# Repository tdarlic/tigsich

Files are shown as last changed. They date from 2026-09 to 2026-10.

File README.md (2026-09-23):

# TIGSICH – index-finger slide remote for IPOTools SuperTIG 200Di

A passive, torch-mounted current control that replaces the IPOTools **FT-47K-CL8** foot pedal.
A **finger bar** under the index finger does both jobs. **Sliding** it moves a slide pot, which sets the welding current.
**Pressing** it clicks a push-on / push-off switch underneath, which starts or stops the arc at any current setting. The concept is the same
as the [6061 Slide Lever](https://www.6061.com/slidelever.htm).

> **Status: design rev 4, not yet prototyped. All board parts are in stock at Mouser (see section 7).** The socket voltages on the machine have **not been
> measured** yet. See [Open items](#open-items--before-first-use).

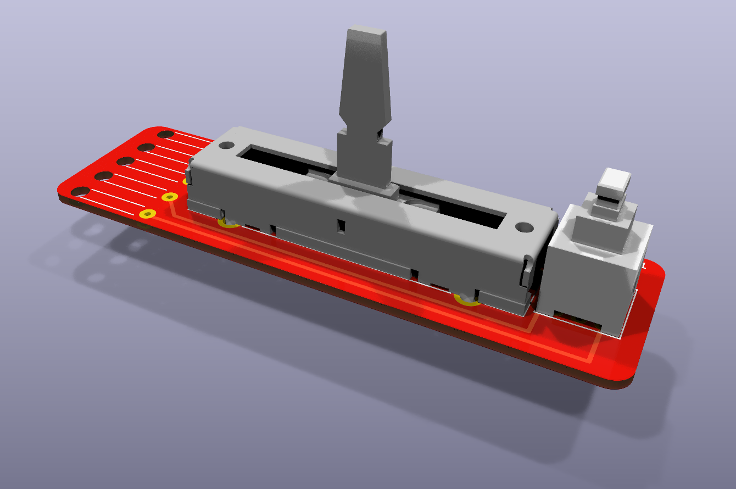
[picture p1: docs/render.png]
3D render of the board


Side view

| Schematic | PCB (top) | 3D top view |
|---|---|---|
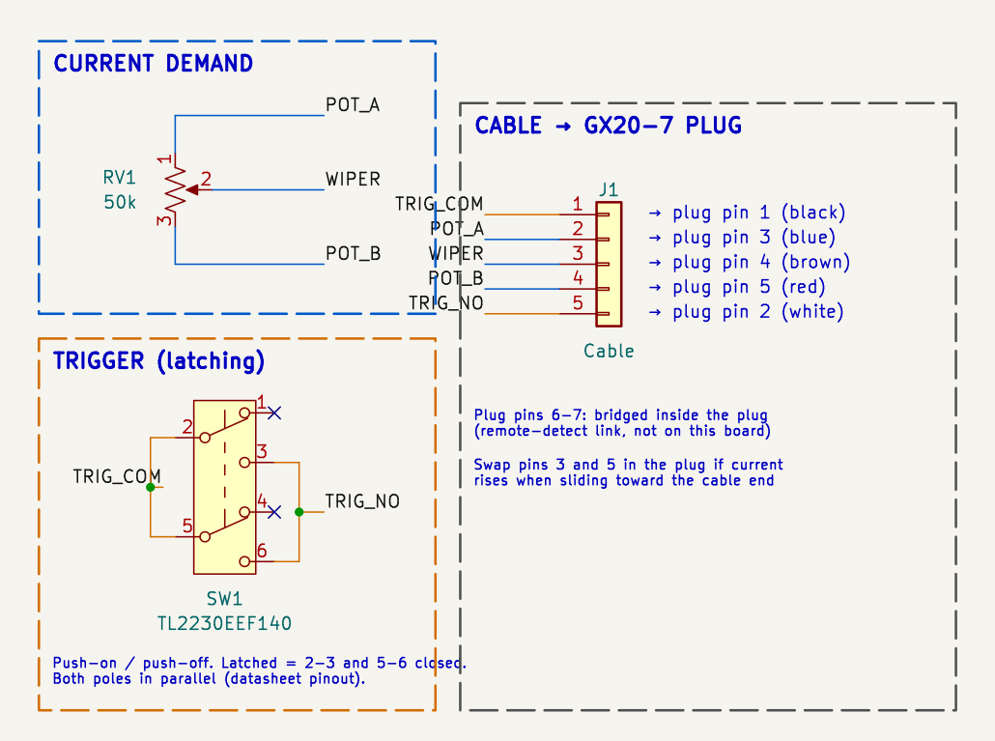
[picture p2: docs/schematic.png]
schematic
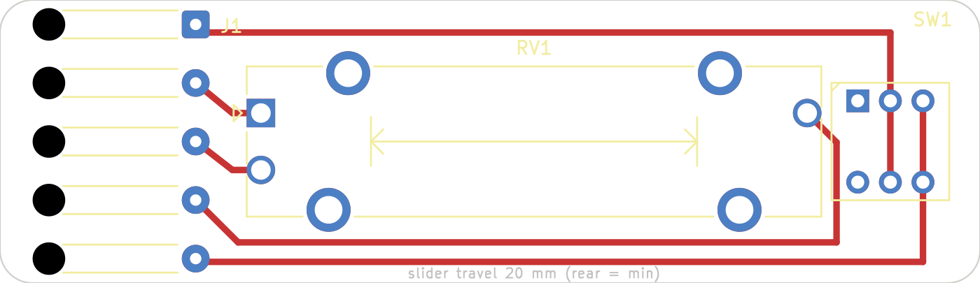
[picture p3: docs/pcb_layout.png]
pcb
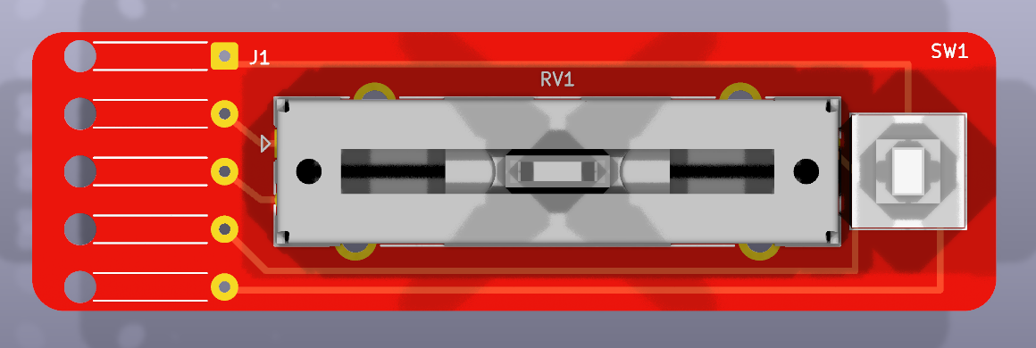
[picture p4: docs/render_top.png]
3d top
|  |  |  |

---

## 1. Machine interface

The machine has a GX20 7-pin remote socket. The pinout is the same one used by AHP/PrimeWeld pedals
(`configuration.jpeg`). It was confirmed by measuring the user's own FT-47K-CL8 pedal:

| Plug pin | Wire colour (diagram) | Function | Measured on FT-47K-CL8 |
|---|---|---|---|
| 1 | black | trigger contact | open → short when pedal pressed |
| 2 | white | trigger contact | 〃 |
| 3 | blue | pot end A | 3–4 and 4–5 swing 0.5 kΩ … 50 kΩ in opposite directions |
| 4 | brown | pot wiper | |
| 5 | red | pot end B | |
| 6–7 | – | remote-detect link | 0 Ω (bridged inside the plug) |

**Decisions based on this:**

- **Pot value 50 kΩ linear.** The pedal model name (47K) and the measurement (≈50 kΩ end to end) agree.
  The ±20 % pot tolerance doesn't matter, because the machine reads the wiper as a *ratio* of the reference voltage.
- **No series trim resistors.** The pedal's 0.5 kΩ minimum is simply the pot's residual resistance. The PTA datasheet
  specifies "500 Ω or 1 % max", which is exactly what the pedal shows.
- **Pins 6–7 are bridged inside the GX20 plug, not on the PCB.** This keeps the cable at 5 cores (thinner and more
  flexible on a torch).
- **The switch itself must latch.** IPOTools states the remote works **only in 2T mode**, so the machine's 4T
  latch can't be used with a momentary button.

### Supply voltage (assumed, not measured)

There is **no power pin** on this plug. The only voltages present are the pot reference (across 3–5) and the
trigger pull-up (across 1–2). Machines of this type typically put 5–15 V there, so the design
**assumes ≈12 V**. Because the design is passive, the voltage only has to stay within the parts' ratings:

| Part | Rating | Margin at 12 V |
|---|---|---|
| PTA2043 (20 mm, linear) | 200 V DC, 0.1 W | 12 V across 50 kΩ = 2.9 mW |
| TL2230 | 30 V DC, 100 mA | fine for a signal-level input |

---

## 2. Architecture

| Option | Outcome |
|---|---|
| Hall sensor + MCU + digital pot | **Rejected.** Needs power, and the plug has no supply pin. It would have to steal current from a 47 kΩ pot reference (≈0.2 mA) or use a battery. It also needs a high-voltage digital pot plus HF-start hardening. |
| Rev 1: finger lever (bell-crank) driving a slide pot | **Rejected on size.** A 35° swing needs a 25 mm drive arm to move the slider 15 mm, which put the lever top about 50 mm above the PCB. The board was 22.5 mm wide. |
| Rev 2: thumb slider + C&K PVA1 EE H4 latching button | **Rejected on height.** The PVA1 is 15 mm tall above the PCB, which set a 2 mm lid and a total height of about 20 mm. The target is under 15 mm. |
| Rev 3: index-finger bar + 15 mm PTA1543 | **Replaced on sourcing.** No 50 kΩ PTA1543 variant is stocked at Mouser (or LCSC). |
| **Rev 4: index-finger bar on the lug of a 20 mm PTA2043, pressing an E-Switch TL2230 latching button (chosen)** | Passive. One bar for both current and arc on/off. **≈14.7 mm** maximum height (bar top), 60.1 × 17.4 × 1.0 mm board. Every part in stock at Mouser. |

**How it's used:**

1. **Set the current:** slide the finger bar. Rear = minimum, front = maximum. It stays where you leave it, because the
   pot's own 30–250 gf friction holds it.
2. **Start the arc:** press the bar down. The switch underneath clicks and latches (plunger and bar stay 1 mm lower), closing pins 1–2.
   This works at **any slider position**, because the bar slides *over* the plunger.
3. **Change current while welding:** slide the bar; the latched switch stays on.
4. **Stop the arc:** press the bar again.

The machine stays in **2T mode**. The trade-off is that nothing stops the arc if you drop the torch: that takes a
deliberate press. The same footprint takes the momentary `TL2230OAF140` (hold to weld) if that's preferred.

---

## 3. Parts

| Ref | Part | Why |
|---|---|---|
| RV1 | **Bourns PTA2043-2015CPB503**: 20 mm travel, 50 kΩ linear, single gang, PC pins, **no centre detent**, 15 mm **metal (CP) lever** | The 15 mm PTA1543 we wanted isn't stocked at Mouser; this one is (≈ 900 pcs). Same series, pinout and ratings, with a 35 mm body (+5 mm board length). 20 mm travel ≈ 10 A/mm on a 200 A machine, which is finer control than 15 mm. **No detent:** the second digit `0` in `-2015…` (a `2` there means a centre detent). The metal **lever lug is cut down** to ≈ 13 mm above the PCB bottom and drilled for the finger-bar hinge pin (A); metal drills more cleanly than the insulated lever. |
| SW1 | **E-Switch TL2230EEF140**: DPDT, latching (EE), 140 gf, 7 × 7 mm, THT | The lowest latching switch with a proper datasheet that I found. Plunger top 12.5 mm above the PCB (11.5 mm latched). 1.0 mm to latch, 1.8 mm full travel. The datasheet shows the pinout and contact states explicitly. |
| J1 | Solder pads with strain-relief holes, **3.6 mm pitch** (`tigsich:SolderWire-0.15sqmm_1x05_P3.6mm…_Relief`, a copy of KiCad's 4 mm version) | No connector to shake loose on a torch. The wire passes up through a 2 mm hole before reaching its pad, so it's held in place. |
| Cable | 5 × 0.14 mm² flexible (insulation OD ≤ 1.5 mm), ~4 m, GX20-7 female plug | Same length as the original pedal (4.3 m). |

**Switches I compared** (button heights above the PCB bottom, for a 1.6 mm PCB; subtract 0.6 mm for the 1.0 mm board):

| Switch | Size (mm) | Button top: unlatched / latched | Verdict |
|---|---|---|---|
| C&K PVA1 EE H4 | 9.8 × 9.2 | 16.6 / 15.1 | Too tall (rev 2) |
| **E-Switch TL2230EEF140** | **7 × 7** | **14.1 / 13.1** | **Chosen** |
| Alps SPEF110100 | 12.2 wide, 9 deep | ≈ 14.6 unlatched | Wider, only 14.5 V DC rated |
| Generic 5.8 mm "self-lock" switches | 5.8 × 5.8 | similar | No trustworthy datasheet |

**Switch wiring:** both poles are in parallel. The TL2230 datasheet shows **rest = 1–2 and 4–5 closed**, and
**pushed / latched = 2–3 and 5–6 closed**. So **2 + 5 → TRIG_COM** and **3 + 6 → TRIG_NO**, and the rest contacts 1 and 4
are left unconnected. The two contacts in parallel give redundancy for a low-level signal.

**Switch life is the weak point.** The TL2230 is rated for **10,000 electrical cycles**, about 5,000 welds (on + off).
That's fine for hobby use, and it's a cheap THT part that's easy to replace.

**Pot life:** the PTA is rated at **15,000 slide cycles**. With a set-and-leave slider (rather than a pedal that moves on
every weld) that lasts a long time. A conductive-plastic slide pot of the same footprint is the upgrade path.

**No filtering or ESD parts on the board.** The original pedal is a bare pot and switch, and the machine's input
circuitry was designed for that. If HF-start interference shows up, the first fix is a shielded cable with the shield
grounded at the machine end.

---

## 4. Mechanics and heights (see `docs/mechanism.svg`)

**The finger bar:**

1. **Hinge at A:** its rear end is hinged on the cut pot lug with a pin (Ø ≈ 1 mm) through the lug, held by two
   clevis ears under the bar. Sliding the bar drags the pot slider.
2. **Resting on the switch:** its front part rests on the TL2230 plunger. The switch's own spring holds the bar up, so
   no extra return spring is needed.
3. **Pressing:** the bar tips about pin A. The distance from A to the switch is 12.5 mm at MAX and 32.5 mm at MIN, so the
   1.8 mm switch travel is a 3.2–8.2° tilt. A rigid joint at A won't work; it has to be a hinge (or a printed flexure).
4. **Finger pad:** at the front end, 38 mm from A, just in front of the switch. Pressing close to the switch keeps the
   lifting force on the pot lug small. (Pressing far in front of the switch levers the lug *up*.)

**Lid features around the switch:**

- **Square bore:** a close-fitting bore round the plunger (3.0 × 2.0 mm head) takes the **sideways friction** as the bar slides across the
  plunger top, so the switch stem isn't bent. A smooth bar underside (polished aluminium, or PTFE tape) helps too.
- **Side rails:** two rails beside the bore keep the bar centred (it can't swing sideways around A).
  Their tops are the **down-stop** at ≈ 1.7 mm switch travel. That's past the 1.0 mm latch point and short of the 1.8 mm end stop.

All heights are measured from the PCB bottom, using nominal datasheet values, with a **1.0 mm PCB**:

| Item | Height |
|---|---|
| PCB | 1.0 mm |
| Pot body top | 7.5 mm |
| TL2230 body top | 8.0 mm |
| Lid (1.5 mm), resting just above the switch body | 8.2 → **9.7 mm** |
| Hinge pin A (in the cut lug) | ≈ 12.2 mm |
| Plunger top = bar underside (unlatched / latched) | 13.5 / 12.5 mm |
| **Finger bar top** (1.2 mm bar), highest point | **≈ 14.7 mm** (13.7 mm latched) |

**The height target (< 15 mm) is met.** A 1.6 mm PCB would add 0.6 mm (≈ 15.3 mm). A 1.5 mm aluminium bar would add another
0.3 mm. Add the housing floor under the PCB (≈ 1–1.5 mm) to get the total thickness on the torch.

**Other housing notes:**

- **Bar overhang:** the bar is 38 mm from A to its front end, so it reaches ≈ 60.8 mm (MIN) to ≈ 80.8 mm (MAX) from the
  rear edge. At MAX it sticks out ≈ 18 mm past the housing front, toward the torch head.
- **Lid slot:** the slot for the pot lug is 20 mm of travel plus the lug width (check on the part, ≈ 5 mm), so about 25 mm long. The clevis
  ears and the bar cover it at every position; a thin skirt on the ears keeps dust out of the pot.
- **Lid fixing:** the lid screws into the pot's two **M2 threaded holes** (on top of the pot frame, 31 mm apart on the PTA2043).
  This clamps lid, pot and PCB into one stack. The PCB has **no mounting holes**, because there's no room at 17.4 mm wide.
  The PCB rests in grooves or on ribs in the housing floor, which also carry the press force.
- **Mounting on the torch:** two strap or zip-tie slots in the housing floor. The cable exits at the rear, alongside the torch hose.

---

## 5. PCB

- **Board:** **60.1 × 17.4 mm**, 2 layers, **1.0 mm** (chosen to keep the finger bar under 15 mm), rounded corners (R2), 0.4 mm tracks (signal-level currents).
  All copper is on the top layer, with no vias. There is no ground plane: the circuit has no ground.
- **Width:** the 17.4 mm is set by the 5-pad cable column: 14.4 mm of pads at **3.6 mm pitch**, plus the 1.7 mm pad size
  and 0.65 mm edge clearance. The 2.0 mm strain-relief holes still take wires with insulation up to 1.5 mm OD, leaving
  1.6 mm of board between neighbouring holes. The pot is 11 mm wide including its tabs, and the switch 7 mm. The two track
  lanes under the pot sit between the pot's mounting tabs and the board edge, with ≥ 0.45 mm clearance.
- **Layout, rear to front (cable → torch head):**
  1. **Cable pads (J1):** at the rear edge.
  2. **Slide pot (RV1):** its slider runs along the board centreline.
  3. **Latching button (SW1):** centred, 0.85 mm in front of the pot body.
- **Routing:** the pot and switch connections that pass alongside the pot run in lanes above and below the pot body.
- **Pot direction:** RV1 pin 1 (the rear end) connects to plug pin 3, so the **rear slider position = wiper next to
  plug pin 3**, i.e. P3–P4 ≈ 0.5 kΩ. If the machine gives *maximum* current at the rear, swap the wires on plug pins 3 and 5.
- **J1 pad order** (top to bottom) is chosen so nothing crosses. It's printed on the **bottom** silkscreen next to each pad:

| J1 pad | Silk | Net | Plug pin | Diagram colour |
|---|---|---|---|---|
| 1 | P1 | TRIG_COM | 1 | black |
| 2 | P3 | POT_A | 3 | blue |
| 3 | P4 | WIPER | 4 | brown |
| 4 | P5 | POT_B | 5 | red |
| 5 | P2 | TRIG_NO | 2 | white |

- **PTA2043 footprint: corrected copy of KiCad's.** KiCad's `Potentiometer_Bourns_PTA2043_Single_Slide` puts pin 3 at
  **33.0 mm** from pin 1, but the datasheet (dimension E) and Bourns' STEP model both give **33.5 mm**. With Ø1.2 mm holes
  and 0.8 mm pins, the library version would not let the pot seat. The project copy
  (`tigsich.pretty/Potentiometer_Bourns_PTA2043_Single_Slide_E33.5`) keeps pins 1/2 where they were, moves pin 3 to
  33.5 mm, and shifts the four mounting tabs and body outline by +0.25 mm, so everything is centred at 16.75 mm as on the part.
- **TL2230 footprint:** it's custom (`tigsich.pretty/SW_E-Switch_TL2230`), because KiCad's library doesn't have one.
  It was made from the datasheet PCB layout (component side): 2 rows of 3 × Ø0.8 mm holes, 2 mm pitch, rows 5 mm apart,
  pin 1 square. The pad numbers match the `Switch:SW_Push_DPDT` symbol: B = common 2/5, A = rest 1/4, C = pushed 3/6.
- **3D models:**
  - **SW1** uses E-Switch's own STEP model (`tigsich.3dshapes/TL2230xxFxxx.stp`, inch units). It is set in the footprint
    with a 90° rotation (the vendor model has its pin rows along Y) and a +0.75 mm Z offset (model origin is 0.75 mm above
    the seating plane). With these, the pins sit centred in the pads and the plunger top is 12.5 mm above the PCB, as in
    the datasheet.
  - **RV1** uses Bourns' STEP model (`tigsich.3dshapes/PTA2043-2015DPB103.stp`, mm). Its "up" is −Z and pin 2 is at +Y,
    so the footprint flips it 180° about X and offsets it by (−0.85, +2.9, 0) mm. That centres the body on the tabs and puts
    all pins and tabs in their holes, with the body seated on the board.
  - **Caution for the housing:** Bourns only offered the model for the **DP** lever variant (`…DPB103`). We order
    **CP** (`PTA2043-2015CPB503`). The body, pins and slot are identical, but **the lever shape differs** (the DP lever in
    the model reaches ≈ 20.7 mm above the PCB top). Take the lever dimensions for the case from the datasheet's CP lever drawing,
    or measure the real part. The lever is cut down anyway.

**Verification:**

- **ERC:** 0 violations.
- **DRC:** 0 violations, 0 unconnected, 0 schematic-parity issues.
- **Tool:** KiCad 10.0.6.

---

## 6. Files

| Path | Content |
|---|---|
| `tigsich.kicad_pro/.kicad_sch/.kicad_pcb` | KiCad project |
| `tigsich.pretty/` | Project footprints: TL2230, corrected PTA2043 (E = 33.5 mm), 3.6 mm pitch cable pads |
| `tigsich.3dshapes/` | Vendor STEP models: TL2230 (E-Switch), PTA2043 DP-lever variant (Bourns) |
| `docs/mechanism.svg` | Scaled side view: finger bar, hinge, switch, heights |
| `docs/schematic.pdf` / `.png` | Schematic exports |
| `docs/render.png`, `docs/render_top.png`, `docs/pcb_layout.png` | 3D renders (KiCad, vendor STEP models) and copper/silk plot |
| `configuration.jpeg` | 7-pin plug pinout reference |

---

## 7. Bill of materials (Mouser)

Stock and prices were checked on 2026-09-23 through the pcbparts MCP (Mouser API, USD).

| Ref | Qty / unit | Spare | Manufacturer part | Mouser no. | Stock | Price (USD) |
|---|---|---|---|---|---|---|
| RV1 | 1 | +2 (lug cutting / drilling trials) | Bourns **PTA2043-2015CPB503** | 652-PTA20432015CPB50 | 893 | 1.76 (1+), 1.35 (10+) |
| SW1 | 1 | +9 (wear part, 10k cycles) | E-Switch **TL2230EEF140** | 612-TL2230EEF140 | 4,614 | 0.85 (1+), 0.75 (10+) |
| – | 1 reel (5,000) | – | YAGEO **RC0603FR-07100KL** (100 kΩ 1 % 0603, general stock, not used on this board) | 603-RC0603FR-07100KL | 5.1 M | 0.003 (5,000+) |

The Mouser order comes to ≈ $30, under Mouser's EU free-shipping threshold (≈ €50). Mouser ships to the EU with duty and VAT included,
so there's no customs agent. Add other stock parts to reach the threshold.

**Not at Mouser** (buy elsewhere):

| Item | Suggested source |
|---|---|
| Cable 5 × 0.14 mm², ~4.3 m | LAPP UNITRONIC LiYY 5x0.14 (LAPP 0028205) at TME, or any flexible 5-core; shielded LiYCY 5x0.14 (0034305) if HF-start noise appears |
| GX20 7-pin female cable plug | Generic "aviation" connector (local shop, Amazon.de/eBay), or reuse the FT-47K-CL8 pedal's plug; bridge pins 6-7 inside |
| PCB 60.1 × 17.4 × 1.0 mm, 2 layers | Any EU/CN PCB fab (thickness 1.0 mm must be specified) |
| Hinge pin Ø 1 mm, M2 screws ×2 (lid → pot), finger bar 1.2 mm | Hardware store / printed or machined parts |

---

## Open items / before first use

1. **Measure the socket.** With the machine on and the pedal unplugged, measure the DC voltage across 3–5, across 1–2, and from
   each pin to the case. It must be **≤ 30 V** on 1–2 for the TL2230. Don't strike an arc (HF start) while probing.
2. **Check the switch.** Before soldering, check with a meter that the TL2230 closes 2–3 (and 5–6) only when latched.
   On the finished board, check that P1–P2 is open when the button is up and closed when it's latched.
3. **Check the pot direction:** the rear slider position should give minimum current. Swap plug pins 3/5 if needed.
4. **Check part dimensions** against real parts. The TL2230 plunger height sets the bar height, and the pot lug is
   cut and drilled to suit the hinge.
5. **Design the housing and bar:** lid with lug slot, plunger bore, side rails and down-stop, M2 screws into the pot,
   finger bar with clevis ears and hinge pin, PCB grooves, strap slots, cable gland.
6. **Check the latch through the bar:** make sure a press anywhere in the 20 mm travel latches and unlatches the switch
   reliably, and that sliding while latched doesn't unlatch it.
7. **Test first on scrap:** check minimum and maximum current, that the latch works with gloves on, and that HF start
   doesn't cause flicker. If it does, use a shielded cable.

## Sources

- [SSC C910-0725 info sheet (same 7-pin pinout)](https://ssccontrols.com/uploads/Product-Information-Sheet-C910-0725-TIG-Foot-Controls.pdf)
- [IPOTools FT-47K-CL8 foot pedal](https://ipotools.eu/product/tig-foot-pedal/)
- [Bourns PTA series datasheet](https://www.bourns.com/docs/product-datasheets/pta.pdf)
- [E-Switch TL2230 datasheet](https://configured-product-images.s3.amazonaws.com/Datasheets/TL2230.pdf)
- [E-Switch TL2230 product page](https://www.e-switch.com/product-catalog/tl2230-series-subminiature-pushbutton-switch)
- [C&K PVA series datasheet (rev 2)](https://www.mouser.com/datasheet/2/240/pva-3050984.pdf)
- [Alps SPEF series (compared)](https://tech.alpsalpine.com/e/products/category/switches/sub/03/series/spef/)
- [6061 Slide Lever (concept reference)](https://www.6061.com/slidelever.htm)

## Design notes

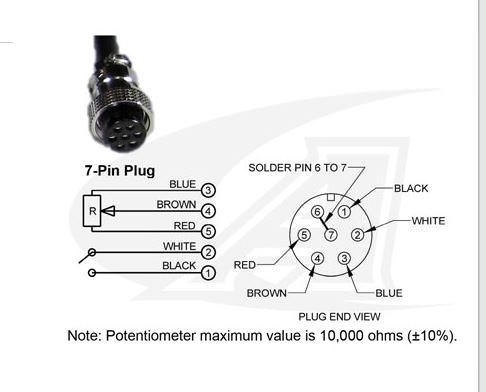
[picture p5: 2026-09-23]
configuration.jpeg

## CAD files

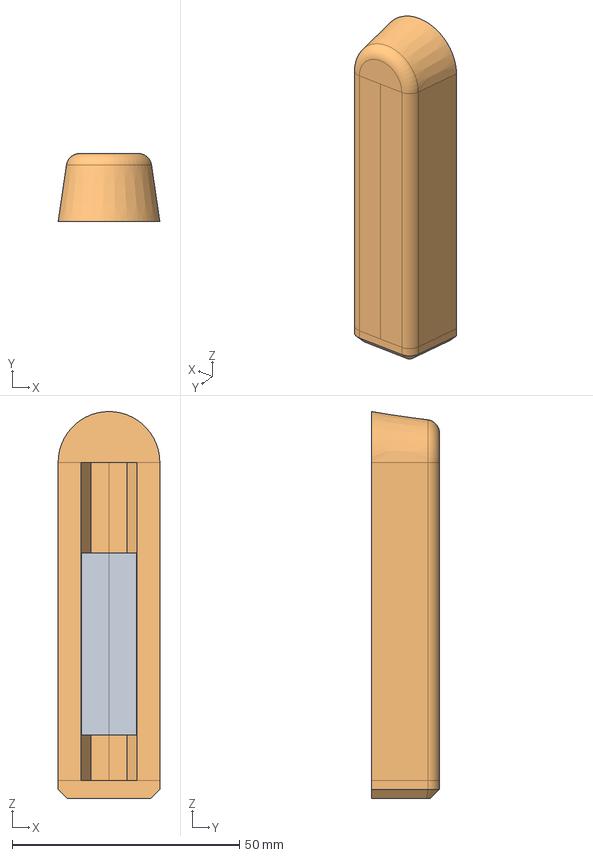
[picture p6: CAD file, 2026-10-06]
hardware/slider_test.step
22.4 x 15.0 x 85.2 mm
Podnozje
botun

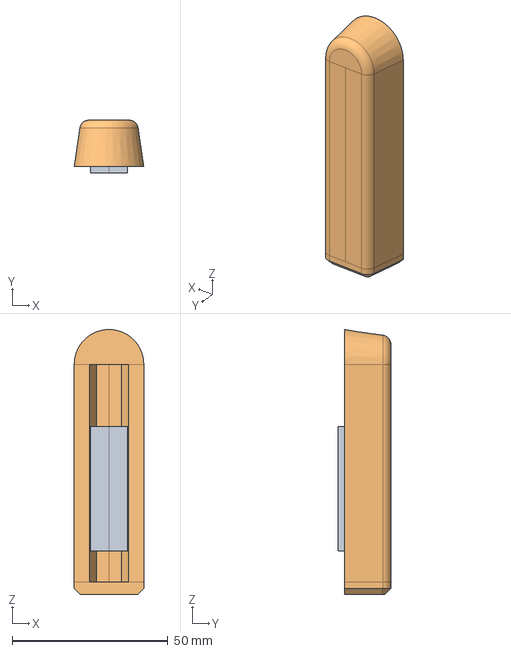
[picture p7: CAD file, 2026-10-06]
hardware/slider_test-Part.step
22.4 x 17.0 x 85.2 mm
Podnozje
botun

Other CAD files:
hardware/slider_test.FCStd
hardware/tigsich.FCStd

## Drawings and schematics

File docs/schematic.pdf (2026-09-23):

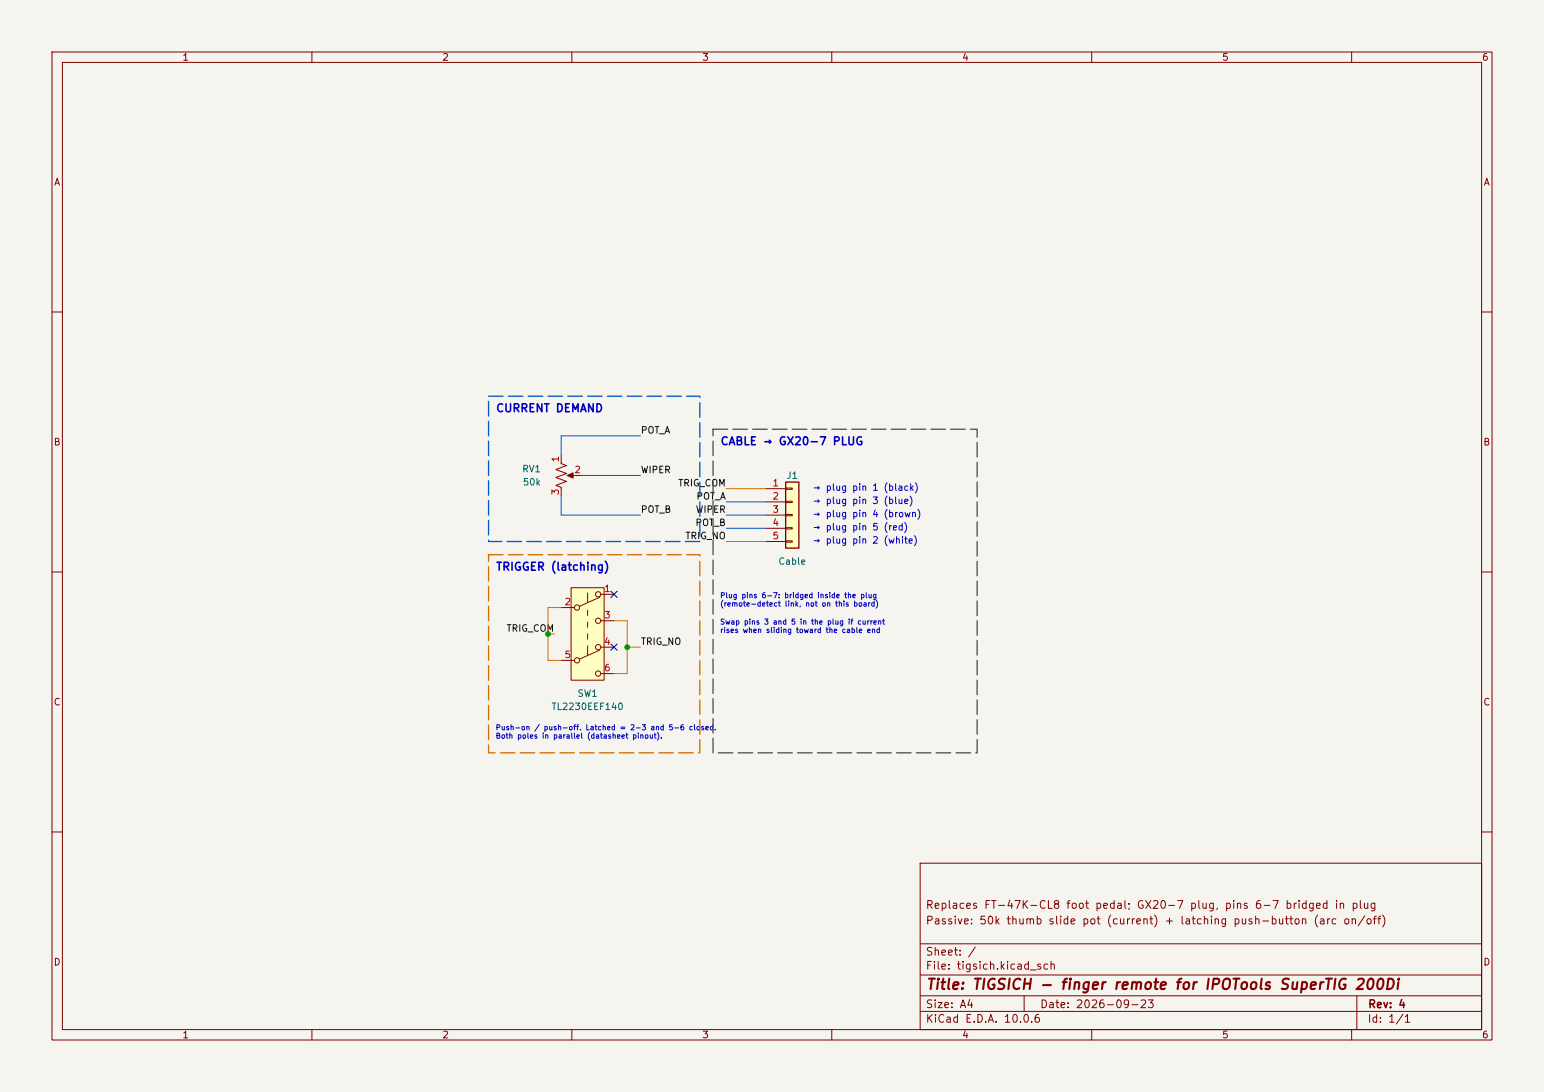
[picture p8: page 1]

(remote-detect link, not on this board) Swap pins 3 and 5 in the plug if current rises when sliding toward the cable end → plug pin 2 (white) → plug pin 5 (red) → plug pin 4 (brown) → plug pin 3 (blue) → plug pin 1 (black)
POT_A
POT_B WIPER

Plug pins 6-7: bridged inside the plug

Push-on / push-off. Latched = 2-3 and 5-6 closed. Both poles in parallel (datasheet pinout).

Replaces FT-47K-CL8 foot pedal; GX20-7 plug, pins 6-7 bridged in plug
Passive: 50k thumb slide pot (current) + latching push-button (arc on/off)

Sheet: /
File: tigsich.kicad_sch
Title: TIGSICH - finger remote for IPOTools SuperTIG 200Di

Size: A4 | Rev: 4
KiCad E.D.A. 10.0.6 | Id: 1/1

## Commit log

2026-09-23 Changed the design to slider
    [tigsich.kicad_pcb, tigsich.kicad_sch]
2026-09-23 Changed the switch
    [tigsich.kicad_pcb, tigsich.kicad_sch]
2026-09-23 Change setup for index slider
    [tigsich.kicad_pcb]
2026-09-23 Switch pot to PTA2043-2015CPB503 (Mouser stock)
    No 50k PTA1543 variant is stocked at Mouser or LCSC, so move to the
    20 mm-travel PTA2043 from the same Bourns series (50k linear, no
    detent, metal CP lever). Pinout and ratings are unchanged.
    - Schematic: RV1 footprint/MPN -> PTA2043_Single_Slide / PTA2043-2015CPB503
    - PCB: board 55.5 -> 60.5 x 19 x 1.0 mm, SW1 moved forward, POT_B reroute
    - 3D: PTA1543_approx.wrl -> PTA2043_approx.wrl (35 mm body)
    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
    [tigsich.kicad_pcb, tigsich.kicad_sch]
2026-09-23 Add real switch CAD model
    [tigsich.kicad_pcb]
2026-09-23 Add real slider CAD model, fix PTA2043 footprint pin spacing
    KiCad's PTA2043 footprint has pin 3 at 33.0 mm; datasheet dim. E and
    the Bourns STEP give 33.5 mm, which would not fit the Ø1.2 mm holes.
    - tigsich.pretty: Potentiometer_Bourns_PTA2043_Single_Slide_E33.5
    (pin 3 -> 33.5 mm, tabs/outline +0.25 mm), Bourns STEP attached
    (rot X 180°, offset -0.85/+2.9/0 mm)
    - Schematic/board: RV1 uses the corrected footprint, POT_B track moved
    - Removed PTA2043_approx.wrl; README, renders and sketch updated
    - Project file updated by KiCad
    - Note: vendor model is the DP-lever variant; we order CP
    [tigsich.kicad_pcb, tigsich.kicad_sch]
2026-09-23 Narrow board to 17.4 mm, move switch closer, add README renders
    - Cable pads: 3.6 mm pitch (project copy of KiCad relief footprint),
    board 60.5 x 19 -> 60.1 x 17.4 x 1.0 mm, bottom track lanes re-spaced
    - SW1 moved 0.4 mm toward the pot (0.85 mm gap)
    - docs/render.png (iso) and docs/render_top.png from vendor STEP models,
    replacing pcb_3d.png; sketch and README dimensions updated
    [tigsich.kicad_pcb, tigsich.kicad_sch]
2026-09-25 add hardware step export file
    [tigsich.step]
2026-10-04 Upgrade file format and add datasheets
    [tigsich.kicad_pcb, tigsich.kicad_sch, tigsich.step]
2026-10-06 Add hardware folder with 3D models of device
    [slider_test-Part.step, slider_test.FCStd, slider_test.step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]
2026-10-06 Make device narrower and longer
    [tigsich.kicad_pcb, tigsich.kicad_sch]
